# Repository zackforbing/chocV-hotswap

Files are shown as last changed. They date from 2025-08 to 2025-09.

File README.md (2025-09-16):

# Aura

# this pcb is tested, but still, use at your own risk!

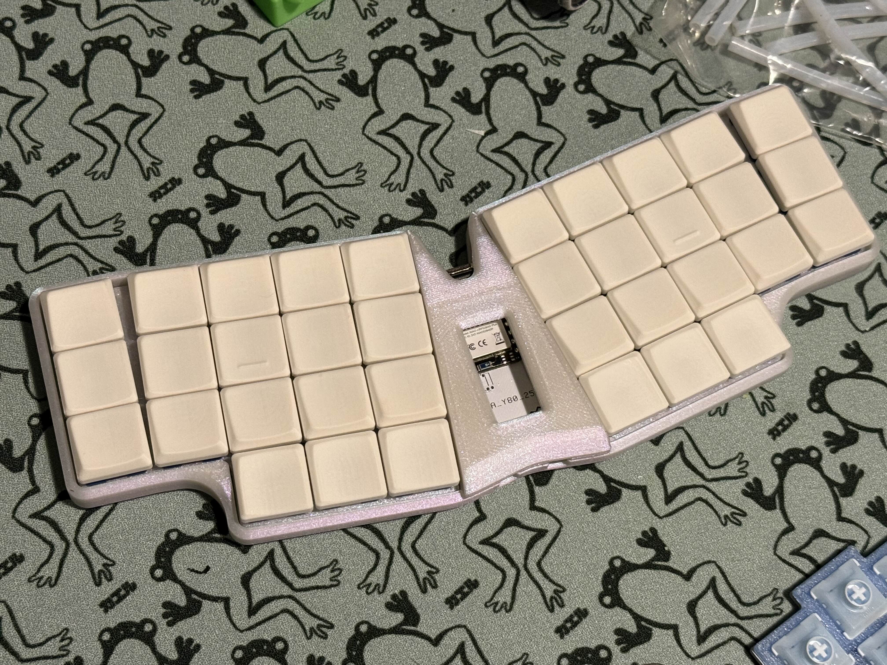
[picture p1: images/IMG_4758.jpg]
aura front

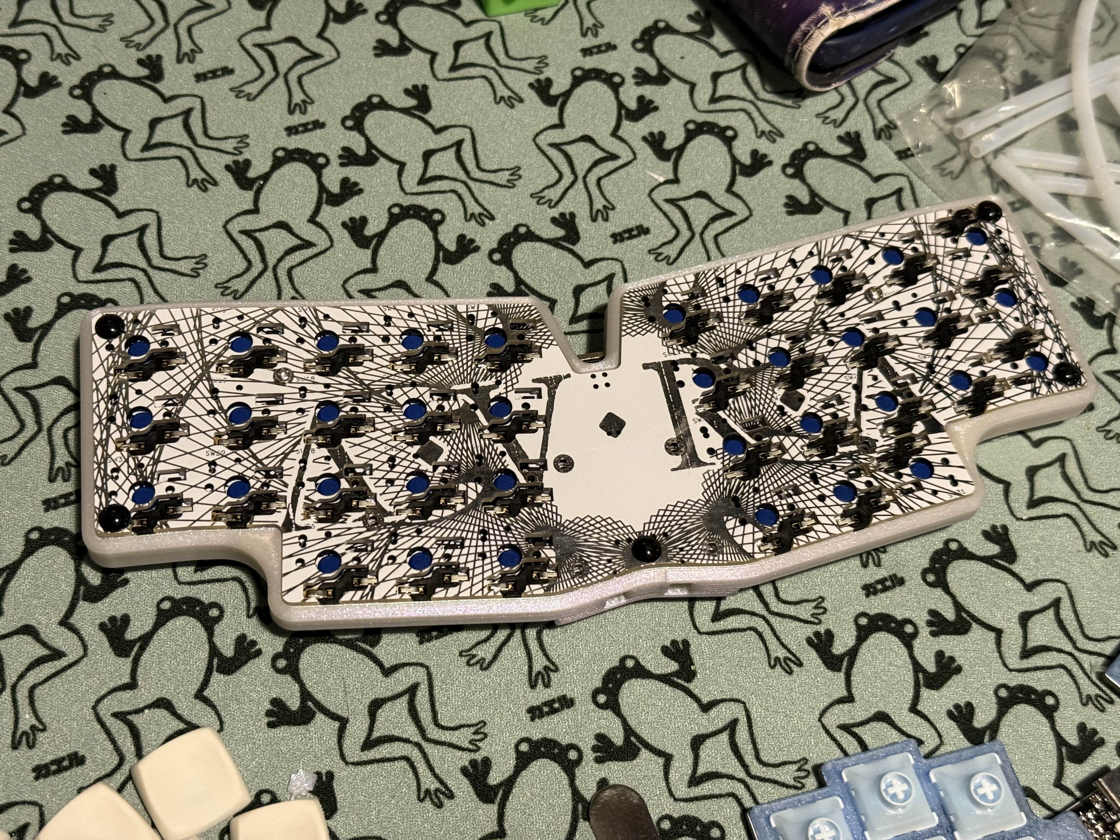
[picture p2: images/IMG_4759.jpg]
aura booty


This is a fork of the original chocV board, adding a dual footprint hotswap/solder choc v1/v2 version, compatibility with xiao nrf52480 plus, and an on-board nice!view connection. ~~The edge cuts had to be modified to fit the hotswap pads, so it won't be compatible with any cases designed for the original~~ just kidding I realized I'm a silly person and I should just flip the footprint upside down for affected switches. The hotswap sockets will protrude from the underside of the bottom plate, so small bumpons are recommended.

A case integrating the bottom plate is in the works.

pcbs have been ordered, built, and confirmed to work.

firmware can be found [here](https://github.com/hahahakeebs/zmk-aura)

original readme preserved below

A 36 key choc keyboard based on the [Horizon](https://github.com/skarrmann/horizon)
construction and a trimmed down [BabyV](https://www.instagram.com/eyeohdesigns/?hl=en) layout!

chocV Lineage

## Horizon + BabyV

The Horizon features a very unique and innovative construction and when I saw it, I knew
I had to build one... but I've become really enamoured with the [Miryoku](https://github.com/manna-harbour/miryoku)
layout on my BabyV. So I decided to mash them together and see what happens.  
Thus the chocV was born!

chocV Family

## Construction

[Skarrmann](https://github.com/skarrmann/horizon) has a wonderful description of
the concept, but the main idea is to generate at least TWO pcb's for the keyboard. One
standard PCB with traces and all the components, and a second which bolts directly
under with cutouts that match all the components on the first to protect them (and your
desk) from damage. This ends up creating a really tidy and very low profile board.

chocV Underside

The specific footprints used and a plugin for KiCad to enable easy generation of the
muiltiple PCB's can be found in the Horizon repo. It's a very clever idea which is executed
exceptionally well. All I did was re-arrange it a bit to get a layout I prefer. I've added
the KiCad files I generated in this repo as an example or jumping off point for others.

## Production

I used JLCPCB, as the original did, and the boards turned out great. If you'd like to order a set of your own, the three gerber zip files are in the /gerbers folder. You'll need one of each to
build a full board and I suggest you take a look through the Horizon repo to get a sense for
the build process.

I've built two complete boards, one based on the Elite-C to serve as a wired board and one
built around a Nice:Nano for wireless functionality.

chocV MCU chocV MCU mounting

## Keymap / Layout

The Miryoku layout is what I use across all my boards. It's very flexible and can be
used/implemented on just about any physical layout. I've used it on split boards mostly, but
when I got the BabyV I feel like I really hit a sweet spot. Splits are great, and they do
feel better when I do a lot of typing, but the BabyV has a great sound, good looks, and
monoblocks are just easier to manage on a desk... it might have a few too many keys, but
nothing is perfect :-)

Miryoku has both a fully supported QMK build system and a work in progress system for ZMK.
If you are looking for a well thought-out minimalist layout, I can't recommend it enough.

chocV Size Comparison

## Build one yourself!

If you are interested in building a chocV, feel free to use the files here and to reach out with
any questions. Happy Keyboarding!

<a href='https://ko-fi.com/brickbots' target='_blank'>Buy Me a Coffee at ko-fi.com

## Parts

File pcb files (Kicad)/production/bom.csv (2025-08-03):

Designator | Footprint | Quantity | Value | LCSC Part #
D1, D10, D11, D12, D13, D14, D15, D16, D17, D18, D19, D2, D20, D21, D22, D23, D24, D25, D26, D27, D28, D29, D3, D30, D31, D32, D33, D34, D35, D36, D4, D5, D6, D7, D8, D9 | D_SOD-123 edge cut | 36 | D
H1, H2, H3, H4, H5, H6, H7, H8 | Mount_M2 | 8 | Hole_Pad
J1 | PinHeader_1x05_P2.54mm_Vertical | 1 | nice!view
SW1, SW10, SW11, SW12, SW13, SW14, SW15, SW16, SW17, SW18, SW19, SW2, SW20, SW21, SW22, SW23, SW24, SW25, SW26, SW27, SW28, SW29, SW3, SW30, SW31, SW32, SW33, SW34, SW35, SW36, SW4, SW5, SW6, SW7, SW8, SW9 | SW_choc_v1v2_HSxSolder no back silk edge cuts only | 36 | SW_Push
SW37 | Panasonic_EVQPUL_EVQPUC | 1 | Reset Switch
SW38 | Panasonic_EVQPUL_EVQPUC | 1 | Soft Off

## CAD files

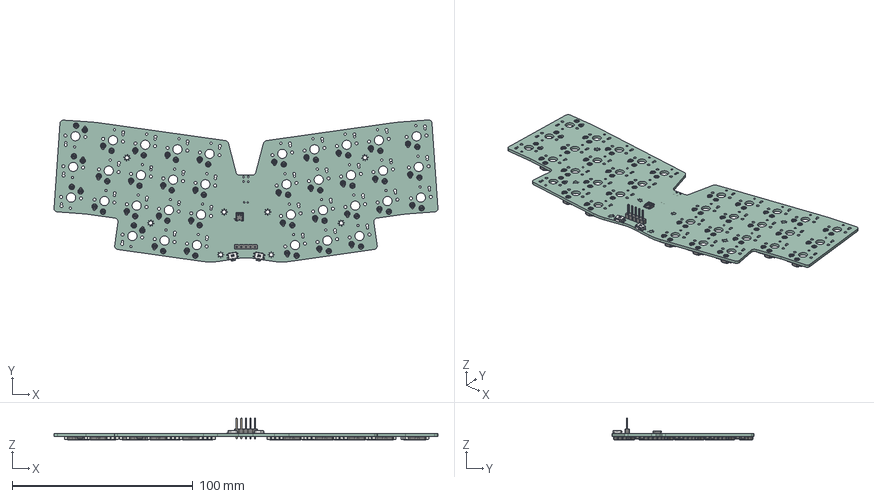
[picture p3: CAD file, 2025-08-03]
pcb files (Kicad)/aura pcb.step
212.5 x 78.7 x 12.1 mm
pin x 72
socket x 36
CON_781710002
EVQPU-LC-02K x 2
PinHeader_1x05_P2.54mm_Vertical
D_SOD-123 x 36
aura_PCB

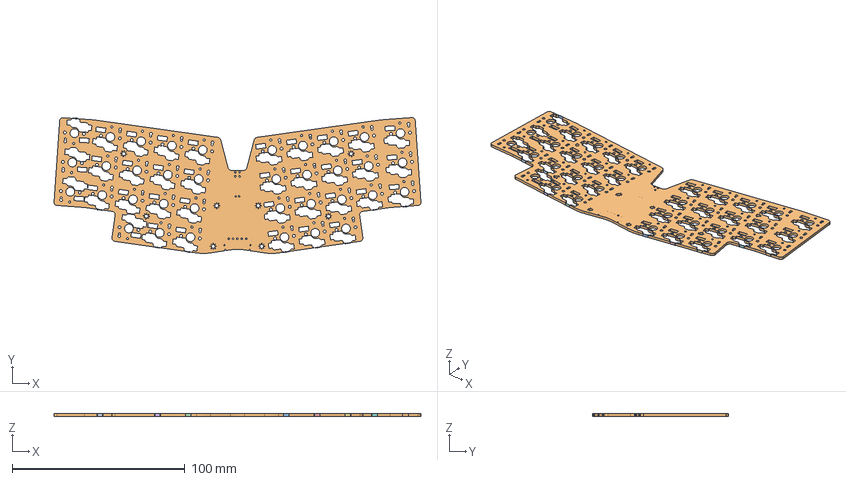
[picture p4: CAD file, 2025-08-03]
pcb files (Kicad)/aura.step
212.5 x 78.7 x 1.51 mm
aura-bottom plate_PCB_1
aura-bottom plate_PCB_2
aura-bottom plate_PCB_3
aura-bottom plate_PCB_4
aura-bottom plate_PCB_5
aura-bottom plate_PCB_6
aura-bottom plate_PCB_7
aura-bottom plate_PCB_8
aura-bottom plate_PCB_9
aura-bottom plate_PCB_10
aura-bottom plate_PCB_11

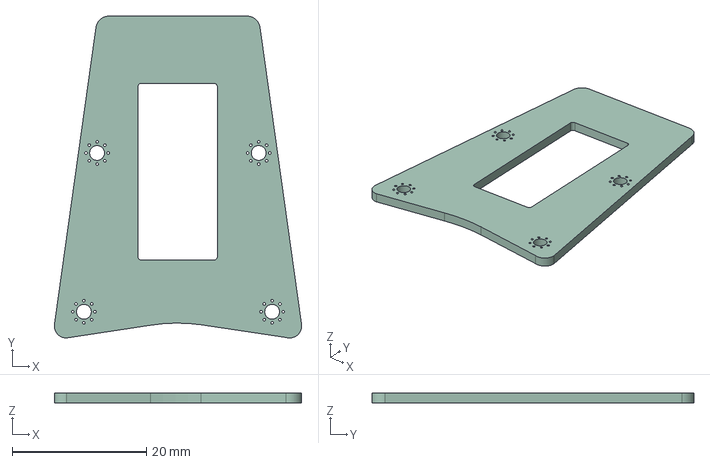
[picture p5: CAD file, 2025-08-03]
pcb files (Kicad)/aura top plate.step
36.8 x 47.9 x 1.51 mm

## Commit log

2025-03-28 init, first proto ready for testing
    [chocV-hotswap-solder.kicad_pcb, chocV-hotswap-solder.kicad_sch]
2025-04-01 add rounded tracks, update readme
    [chocV-hotswap-solder.kicad_pcb]
2025-04-04 added prod files
    [bom.csv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]
2025-06-03 pcb production ready
    [aura-top plate.kicad_pcb, aura.kicad_sch, bom.csv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]
2025-06-17 potentially done, still need to cleanup
    [aura.kicad_sch, bom.csv, designators.csv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]
2025-06-17 new gerbs
    [bom.csv, designators.csv, positions.csv]
2025-08-03 moved some things around
    [aura pcb.step, aura top plate.step, aura-top plate.kicad_pcb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]
2025-09-16 moved stuff, added images of proto
    [aura.kicad_sch]
